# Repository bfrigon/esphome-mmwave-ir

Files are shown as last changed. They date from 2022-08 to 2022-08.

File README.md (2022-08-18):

DISCLAIMER!
-----------

The idea of combining these two sensors is not mine. After watching the following video from "Everything Smart Home" channel on Youtube (https://www.youtube.com/watch?v=VEqWlOeJ2YA&t=62s), i decided to develop my own board. 

This is still a work in progress. 

Description
-----------

This is a presence detection sensor for ESPHome which combine both a PIR motion and mmWave sensor. The PIR sensor, has a faster response time to movement but lack the ability to reliably detect small movements. On the other end, the mmWave sensor is able to reliably detect the smallest movements. Standing still in front of the sensor, it will still be able to detect movement just from breathing. Since it uses radio waves, it can detect a person behind a shower curtain which the PIR is unable to do making it the prefect sensor for bathrooms. However, the initial detection when entering the room can sometime be delayed a bit, enough to be noticeable. By combining these two sensor types, we get the best of both world.

I designed the board so that the PIR sensor can be mounted either facing the same direction as the mmWave sensor but also in a downward position. This way, the enclosure can be mounted near the ceiling above the door so that the PIR can detect a person entering the bathroom without detecting someone walking by in the hallway. 

Components
----------

- DFRobot SEN0395 mmWave sensor
- PIR motion sensor
- SHT45 Temperature/humidity sensor
- ESP32-C3
- USB-C (for power only)

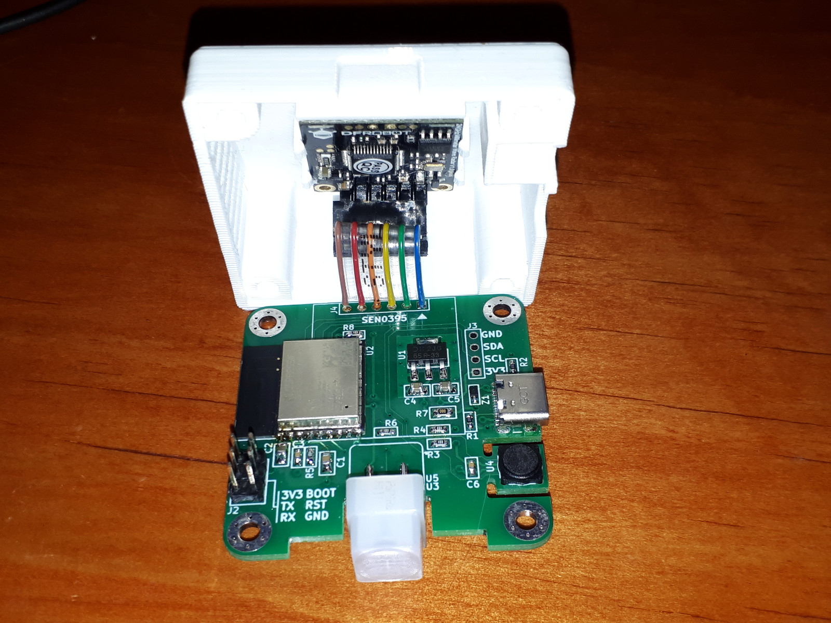
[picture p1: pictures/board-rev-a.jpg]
Board (Revision A)


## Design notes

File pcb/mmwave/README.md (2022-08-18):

### Bill of material ###

```
Date    : 2022-07-29
Doc. ID : MMIR-SCH-01
Project : Esphome Mmwave Sensor / Ir Sensor
Title   : Main Board

Part #  : MMIR-V1
REV.    : B

Components : 25
```

------------------------------------------------------------------------------------------------------------------------

| Qty | Ref. | Description | Value | Part # | Footprint |
|-----|---|---|---|---|---|
| 1 | H5 | | SF2 | - | SF2-SensorCap |
| 1 | J3 | Header - Single Row - 4 Pos | I2C | - | HDR-M-1x04 |
| 1 | J4 | Header - Single Row - 6 Pos | MMW_SENSOR | - | HDR-M-1x06 |
| 1 | J2 | Header - Dual Row - 6 Pos | PROG | - | HDR-M-2x03 |
| 1 | J5 | Header - Single Row - 2 Pos | VIN | - | conn-jst:B2B-PH-K |
| 1 | J1 | USB Connector - Type C - 16 Contacts | - | USB4105-GF-A | GCT_USB4105-GF-A |
| 1 | U1 | 600mA CMOS LDO Regulator with enable | - | AP7365-33ERG-13 | SOT-223 |
| 1 | U3 | PIR Motion sensor | - | EKMB1310111K | PIR-EKMB1310111K-EDGE |
| 1 | U2 | ESP32-C3 Module, 4MB SPI flash, PCB antenna | - | ESP32-C3-WROOM-02 | ESP32-C3-WROOM |
| 1 | U4 | Temperature and humidity sensor | - | SHT45-AD1B-R2 | smt-dfn:DFN4 |
| 1 | R7 | Resistor | 0 | - | SMT-0805 |
| 2 | C3, C6 | Capacitor | 100nF | - | SMT-0603 |
| 5 | R3-R6, R8 | Resistor | 10k | - | SMT-0603 |
| 1 | C2 | Capacitor | 10uF | - | SMT-0805 |
| 3 | C1, C4-C5 | Capacitor | 1uF | - | SMT-0805 |
| 2 | R1-R2 | Resistor | 5.1k | - | SMT-0603 |
| 1 | Z1 | ESD Supressor | CDSOD323-T05C | - | smt:SOD-323-NP |

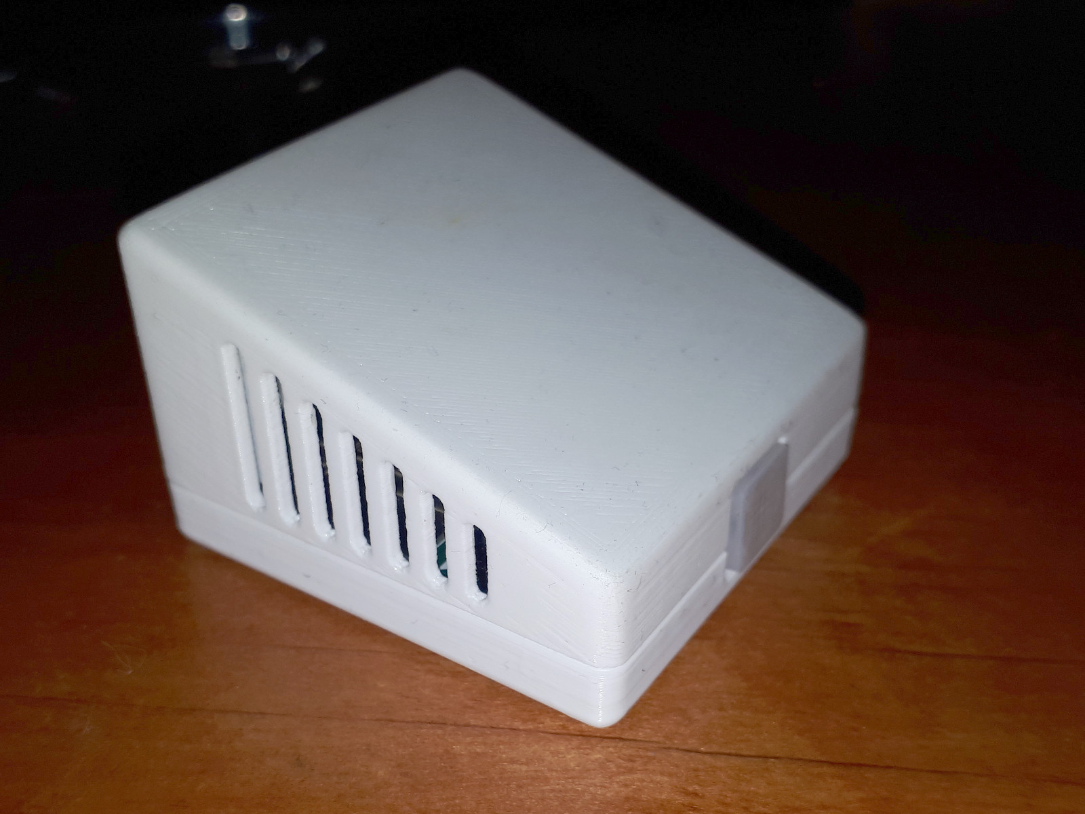
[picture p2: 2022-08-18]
pictures/enclosure.jpg

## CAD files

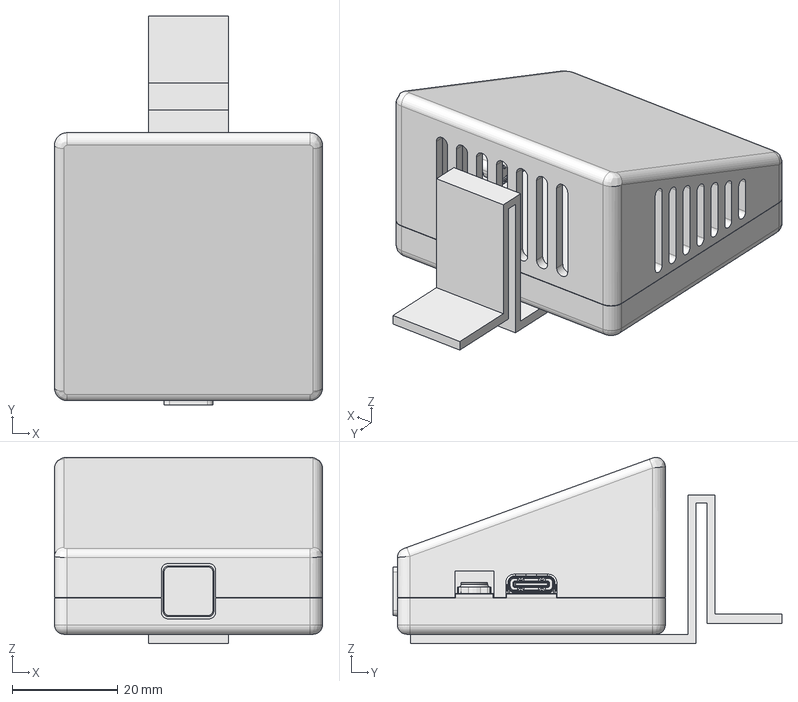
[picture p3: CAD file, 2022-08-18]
enclosure/assembly.FCStd
50.8 x 73.7 x 35.3 mm
cover_001
mainboard1_001
base_001
sen0395_001
bracket-drop-ceiling_001

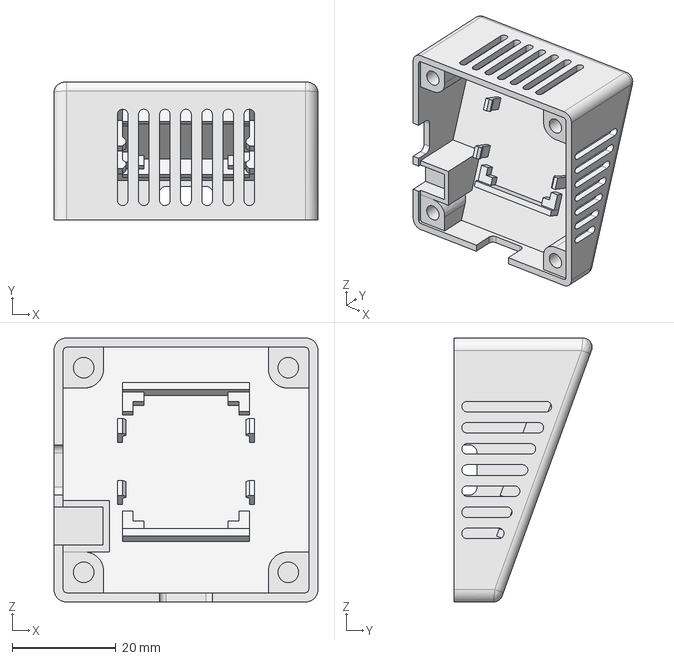
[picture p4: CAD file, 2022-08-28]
enclosure/base.FCStd
50.8 x 26.6 x 50.8 mm

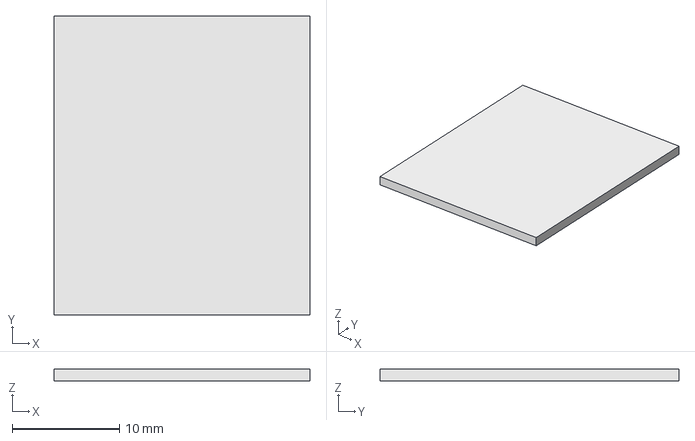
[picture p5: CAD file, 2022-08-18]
enclosure/components/sen0395.FCStd
23.9 x 27.9 x 1.14 mm

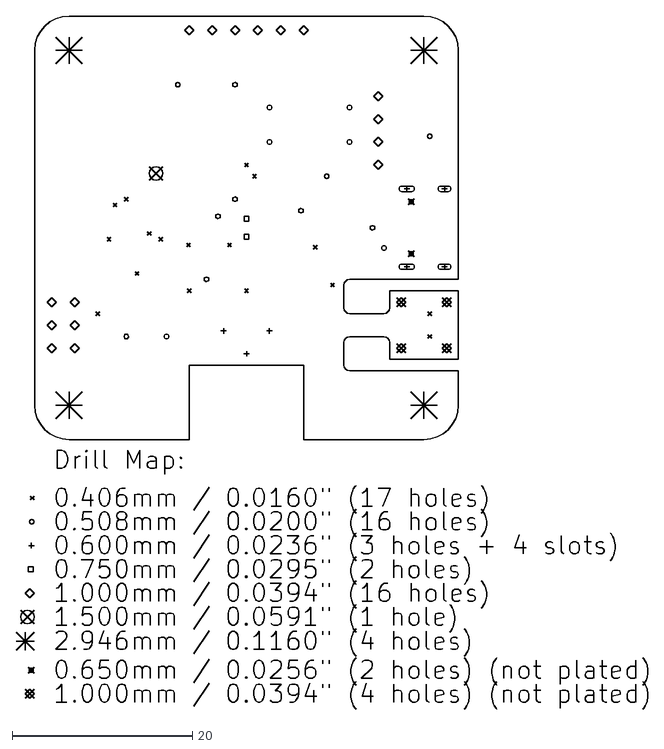
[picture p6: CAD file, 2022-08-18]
pcb/mmwave/gerber/mmwave-drl_map.dxf
70.1 x 76.9

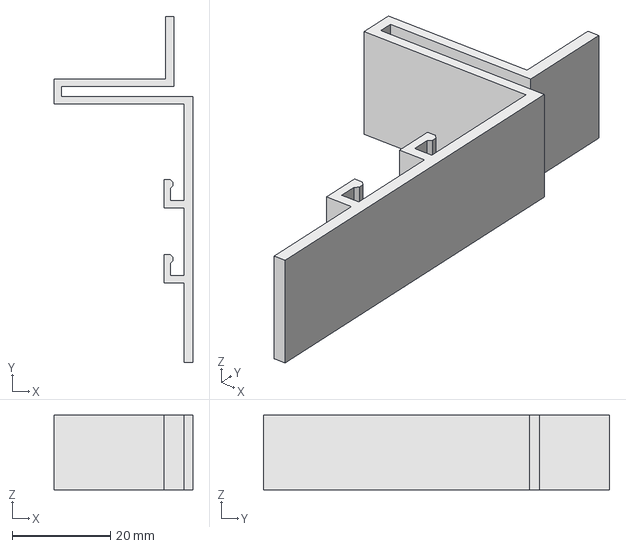
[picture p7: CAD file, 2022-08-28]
enclosure/bracket-drop-ceiling.FCStd
28.2 x 70.4 x 15.2 mm

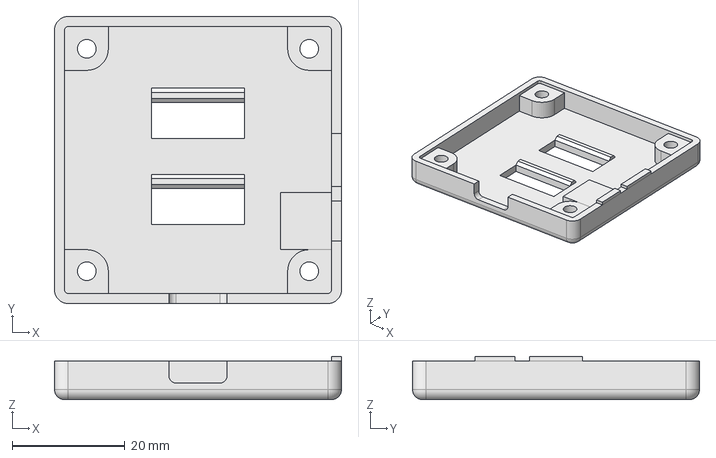
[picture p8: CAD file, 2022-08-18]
enclosure/cover.FCStd
50.8 x 50.8 x 7.62 mm

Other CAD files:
enclosure/stl/base.stl
enclosure/stl/bracket-drop-ceiling.stl
enclosure/stl/cover.stl

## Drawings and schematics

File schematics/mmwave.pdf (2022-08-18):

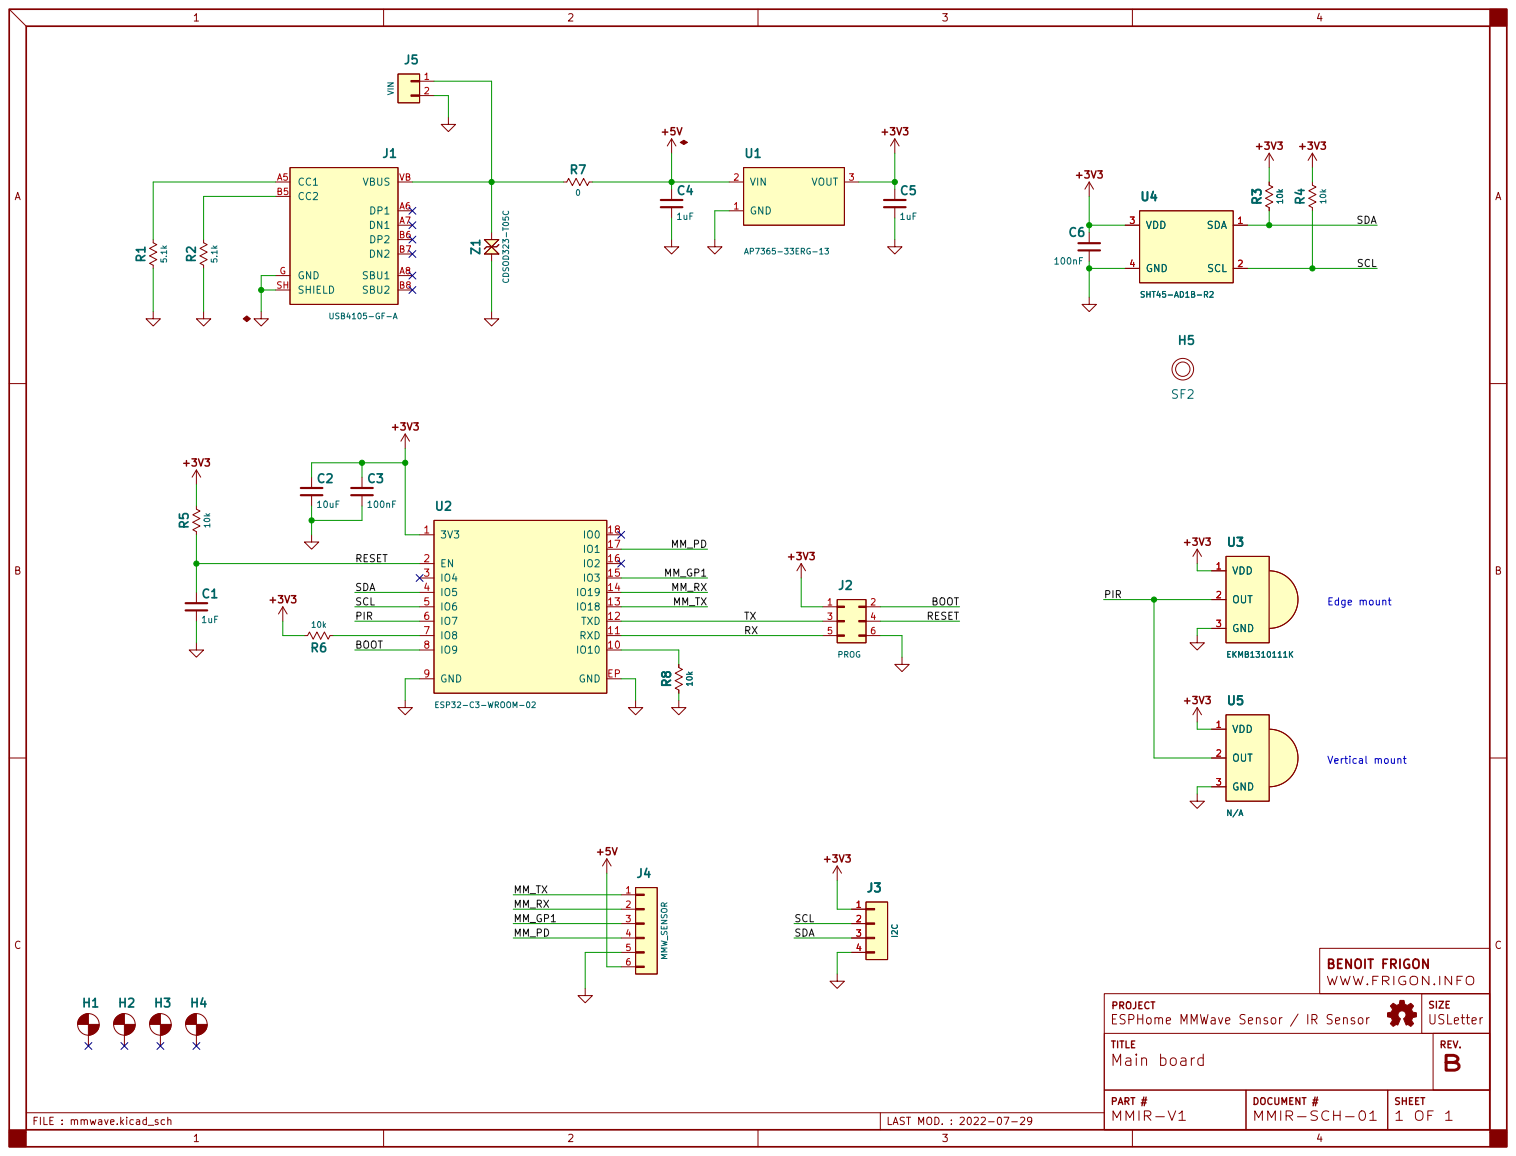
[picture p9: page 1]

SCL SDA RESET SCL PIR

BC ESPHome MMWave Sensor / IR Sensor

TITLE WWW.FRIGON.INFO

REV. PROJECT Main board

PART # | | | B

DOCUMENT # MMIR-V1 | SHEET MMIR-SCH-01

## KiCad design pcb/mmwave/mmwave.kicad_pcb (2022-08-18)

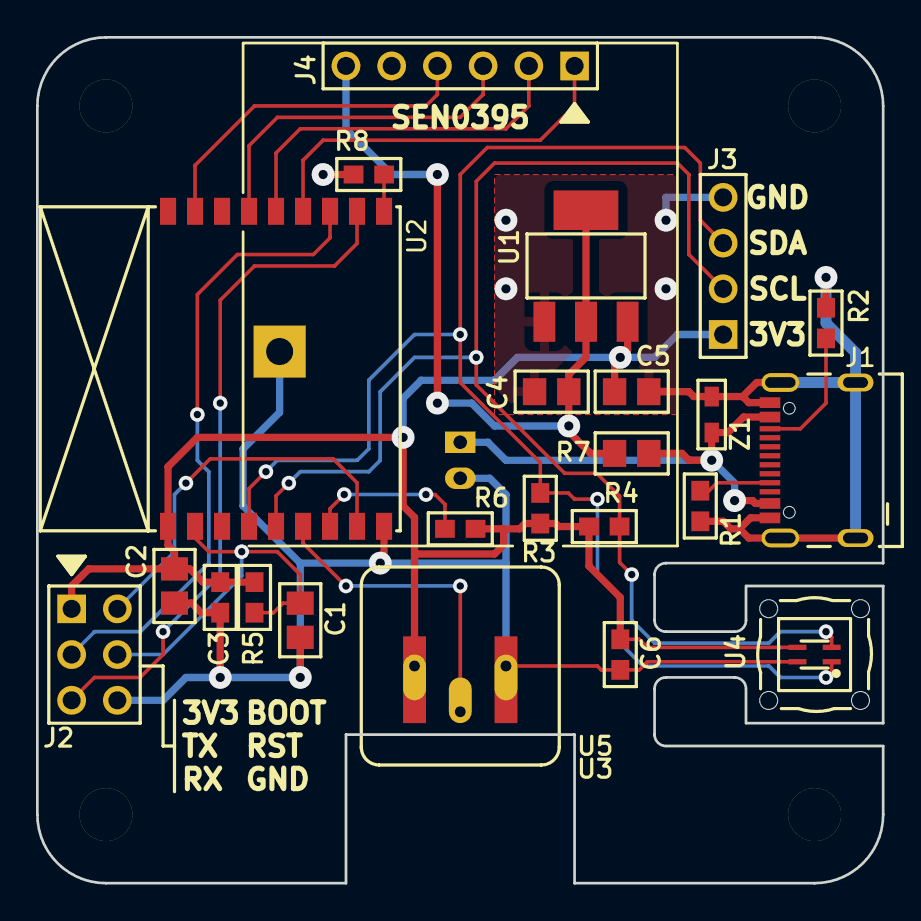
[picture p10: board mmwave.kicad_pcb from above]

Board: 2 copper layers, 47.0 x 47.0 mm, 30 parts (1 on the bottom side), 19 nets.

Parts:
C1, C4, C5: 1uF; C-0805
C2: 10uF; C-0805
C3, C6: 100nF; C-0603
H1, H2, H3, H4: Hole; Hole-Screw-NP-#4
H5: SF2; SF2-SensorCap
J1: USB4105-GF-A; GCT_USB4105-GF-A
J2: PROG; HDR-M-2x03
J3: I2C; HDR-M-1x04
J4: MMW_SENSOR; HDR-M-1x06
J5: VIN; B2B-PH-K
R1, R2: 5.1k; R-0603
R3, R4, R5, R6, R8: 10k; R-0603
R7: 0; FER-0805
U1: AP7365-33ERG-13; SOT-223
U2: ESP32-C3-WROOM-02; ESP32-C3-WROOM
U3: EKMB1305111K; PIR-EKMB1310111K-EDGE
U4: SHT4X; DFN4
U5: N/A; PIR-EKMB1310111K
Z1: CDSOD323-T05C; SOD-323-NP

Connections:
+3V3: C2.2, C3.2, C5.2, C6.2, J2.1, J3.1, R3.2, R4.2, R5.2, R6.2, U1.3 (VOUT), U2.1 (3V3), U3.1 (VDD), U4.3 (VDD), U5.1 (VDD)
+5V: C4.2, J4.6, R7.2, U1.2 (VIN)
/BOOT: J2.2, U2.8 (IO9)
/MM_GP1: J4.3, U2.15 (IO3)
/MM_PD: J4.4, U2.17 (IO1)
/MM_RX: J4.2, U2.14 (IO19)
/MM_TX: J4.1, U2.13 (IO18)
/PIR: U2.6 (IO7), U3.2 (OUT), U5.2 (OUT)
/RESET: C1.2, J2.4, R5.1, U2.2 (EN)
/RX: J2.5, U2.11 (RXD)
/SCL: J3.2, R4.1, U2.5 (IO6), U4.2 (SCL)
/SDA: J3.3, R3.1, U2.4 (IO5), U4.1 (SDA)
/TX: J2.3, U2.12 (TXD)
GND: C1.1, C2.1, C3.1, C4.1, C5.1, C6.1, J1.G (GND), J1.SH (SHIELD), J2.6, J3.4, J4.5, J5.2, R1.1, R2.1, R8.1, U1.1 (GND), U2.9 (GND), U2.EP (GND), U3.3 (GND), U4.4 (GND), U5.3 (GND), Z1.1
unnamed: J1.A5 (CC1), R1.2
unnamed: J1.B5 (CC2), R2.2
unnamed: J1.VB (VBUS), J5.1, R7.1, Z1.2
unnamed: R6.1, U2.7 (IO8)
unnamed: R8.2, U2.10 (IO10)

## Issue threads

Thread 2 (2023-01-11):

KiCad Files

florianmulatz, 2023-01-11:
Hi Benoit,

Would you mind sharing the KiCad Files? I want to maybe reuse your PCB-Design for myself as well!

Cheers
Florian

florianmulatz, 2023-01-11:
Closed - because I've overseen that the files are already there :)

Closed 2023-01-11.

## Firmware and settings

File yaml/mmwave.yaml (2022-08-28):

#####################################################################

substitutions:
  node_name: "esp-sen-bathroom"
  node_description: "Bathroom sensor"
  hass_entity_prefix: "Bathroom sensor"
  

#####################################################################


#####################################################################
#
# System
#
#####################################################################
esphome:
  name: $node_name
  comment: $node_description
  platformio_options:
    board_build.flash_mode: dio
    
  on_boot:
    priority: 250.0
    then:
      - switch.turn_on: mmwave_cfg_need_update

preferences:
  flash_write_interval: 30s    

esp32:
  board: esp32-c3-devkitm-1
  framework:
    type: esp-idf

logger:

api:

ota:
  password: !secret ota_pwd_esp-sen-bathroom
  id: my_ota

wifi:
  ssid: !secret wifi_ssid
  password: !secret wifi_password



#####################################################################
#
# Peripherals
#
#####################################################################
uart:
  id: uart_bus
  tx_pin: GPIO19
  rx_pin: GPIO18
  baud_rate: 115200
  debug:
    direction: BOTH
    dummy_receiver: true
    after:
      delimiter: "\n"
    sequence:
      - lambda: UARTDebug::log_string(direction, bytes);

i2c:
  sda: 5
  scl: 6
  scan: true
  id: bus_a



#####################################################################
#
# Timers
#
#####################################################################
interval:

  #-------------------------------------------------
  # Check if mmWave config need to be pushed
  #-------------------------------------------------
  - interval: 1sec
    then:
    - if:
        condition:
          - switch.is_on: mmwave_cfg_need_update
          - not:
            - script.is_running: update_mmwave_config
        then:
          - script.execute: update_mmwave_config



#####################################################################
#
# Binary sensors
#
#####################################################################
binary_sensor:

  #-------------------------------------------------
  # mmWave occupency status
  #-------------------------------------------------
  - platform: gpio
    name: "$hass_entity_prefix Occupancy"
    device_class: occupancy
    pin:
      number: GPIO1
      mode: INPUT_PULLDOWN
  
  #-------------------------------------------------
  # IR motion detection status
  #-------------------------------------------------
  - platform: gpio
    name: "$hass_entity_prefix IR Motion"
    device_class: motion
    pin:
      number: GPIO7
      mode: INPUT_PULLDOWN
    filters:
      - delayed_off: 1000ms



#####################################################################
#
# Number sensors
#
#####################################################################
number:

  #-------------------------------------------------
  # mmWave max detection distance
  #-------------------------------------------------
  - platform: template
    name: "$hass_entity_prefix Distance"
    id: mmwave_range
    entity_category: config
    icon: mdi:signal-distance-variant
    min_value: 15
    max_value: 1350
    initial_value: 315
    restore_value: true
    optimistic: true
    step: 15
    unit_of_measurement: cm
    mode: box
    set_action:
      - switch.turn_on: mmwave_cfg_need_update
      
  #-------------------------------------------------
  # mmWave output latency
  #-------------------------------------------------
  - platform: template
    name: $hass_entity_prefix Latency
    id: mmwave_latency
    entity_category: config
    icon: mdi:timer-outline
    min_value: 0
    max_value: 65000
    initial_value: 12500
    restore_value: true
    optimistic: true
    step: 25
    unit_of_measurement: ms
    mode: box
    set_action:
      - switch.turn_on: mmwave_cfg_need_update
      
  #-------------------------------------------------
  # mmWave detection sensitivity
  #-------------------------------------------------
  - platform: template
    name: $hass_entity_prefix Sensitivity
    id: mmwave_sensitivity
    entity_category: config
    min_value: 0
    max_value: 9
    initial_value: 7
    restore_value: true
    optimistic: true
    mode: box
    step: 1
    set_action:
      - switch.turn_on: mmwave_cfg_need_update
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

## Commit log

2022-08-18 Updated BOM and schematic
    [mmwave.kicad_pcb, mmwave.kicad_sch]
2022-08-28 Updated enclosure
    [base.FCStd, base.stl, bracket-drop-ceiling.FCStd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]
